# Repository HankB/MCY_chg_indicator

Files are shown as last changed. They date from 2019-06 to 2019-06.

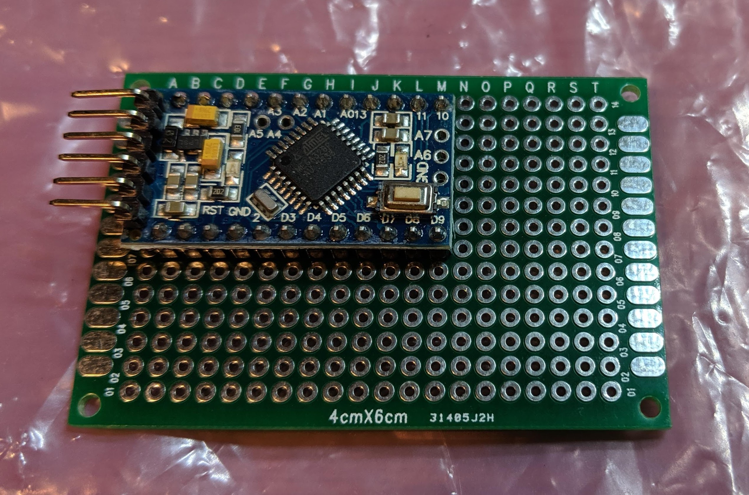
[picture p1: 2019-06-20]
IMG_20190619_212652.jpg

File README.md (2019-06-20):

# Control RGB color based on input voltage

## Motivation

When the electrical charging system on a motorcycle is heavily loaded, it may not keep the battery fully charged. The first symptom of that is that voltage will drop continuously until it is no longer sufficient to keep the engine running. The second symptom is that the motorcycle will stop running and/or may not restart. If there is an indication of system voltage, the issue can be dealt with (by shedding load) before the moto stops running. This project will produce an indication using an Arduino/AVR to monitor voltage and transition an RGB LED from green through yellow and to red to indicate charging status.

Secondary motivation is to help mark the passage of time. Many traffic lights won't detect the presence of a motorcycle and after some time it is allowed to proceed when traffic permits. Flash one, two, three and four times to mark passage of a minute. (15 second intervals.)

## Functionality

* Vary the color of the RGB LED from red -> yellow -> green to indicate system voltage.
* Flash (blip) the LED periodically to mark the passage of time.

## Hardware

* Arduino Pro Mini. (Or bare ATMEGA328P chip on PCB)
* Voltage regulator and filtering capacitors to convert nominal 12V power to 5.0V to power the system. L7805CV regulator with 0.47µF input and 0.22µF output filtering capacitors.
* Resistor voltage divider to reduce the moto system voltage to <5.0V needed for the ADC on the AVR. (1x 2.4KΩ and 1x 1.2KΩ resistors to provide a divider that will produce 5.0V from 15.0V.)
* Input protection for the ADC consisting of 1N5231B (5.1V) Zener diode with 820Ω resistor. [0]
* RGB LED with 3 2KΩ series resistors. That's fairly high resistance but otherwise the LED will be excessively bright during the day. ()

Connect the middle leg of the volume fader to A0 with outer legs connected to ground and 5V to provide a 0-5V analog input.
Connect the longest leg of the RGB LED to ground. When the ground is toward the left, the remaining pins are red, green and blue left to right respectively. Connect the LED inputs to the digital outputs indicated in the code.

## Other information

General description https://docs.google.com/document/d/1oGInpiPI6TI1JvXcmjz_O_Tvbv5o_kn_NtnWW1Aht5o/edit?usp=sharing
Resistor vs. ADC reading calculations https://docs.google.com/spreadsheets/d/1I-rtjzvy2xRRpHdrsMQctPhc0Ry49aa2tnfBnYBoY4o/edit?usp=sharing

## TODO

* Average several input readings for better noise rejection. - done
* Develop scaled analog input with protection - done on mock-up.
* Develop VR to power board from ~12V auto power - done on mock-up.
* Build a custom board with Pro Mini, power supply, analog input conditioning and outputs for the RGB LED. 

## Errata

When using the Inland Pro Mini 5V and providing it with 5V to Vcc, it reads full scale at ~4.7V. Treating the ADC as if it has a reference voltage of 4.7V produces readings over the range more closely match what is read using a DVM.

[0]I've studied the data sheet for the Zener diode and have no idea if the paired resistor is the right value to provide protection.

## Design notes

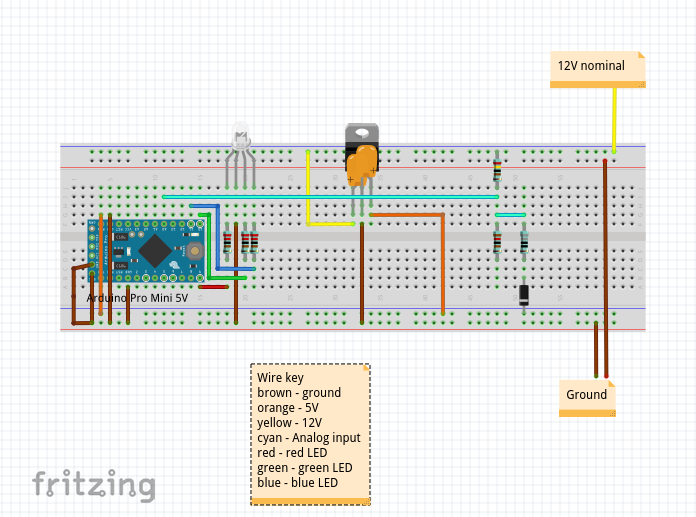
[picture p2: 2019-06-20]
breadboard.png

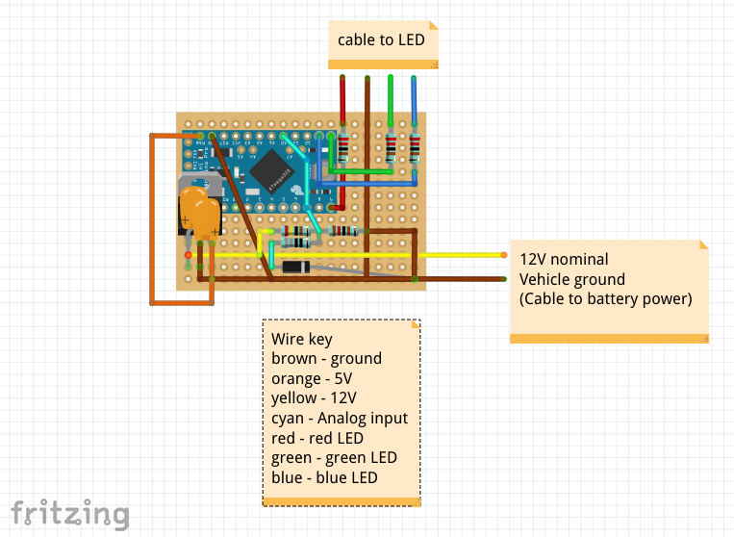
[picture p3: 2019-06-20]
protoboard.png

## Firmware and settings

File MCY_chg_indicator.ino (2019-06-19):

/*
  This sketch began life as the "Analog Input" example. Little of the original remains.
  created by David Cuartielles
  modified 30 Aug 2011
  By Tom Igoe

  This example code is in the public domain.

  http://www.arduino.cc/en/Tutorial/AnalogInput

  Monitor an analog input and illuminate an RGB LED to indicate evaluation of
  the charging voltage. Input volgate is scaled 1:3 so that 15V from the
  charging system would present 5.0V at the analog input.

  See https://docs.google.com/document/d/1oGInpiPI6TI1JvXcmjz_O_Tvbv5o_kn_NtnWW1Aht5o/edit?usp=sharing
  and https://docs.google.com/spreadsheets/d/1I-rtjzvy2xRRpHdrsMQctPhc0Ry49aa2tnfBnYBoY4o/edit?usp=sharing
  for further information.

*/

// thresholds based on apparent 4.7V ADC reference voltage when Pro Mini is provided with Vcc = 5.0V
static const uint16_t high = 1000;
static const uint16_t good = 921;
static const uint16_t marginal = 887;
static const uint16_t bad = 682;
static const uint16_t spread = good - bad;

// I really wish Arduino didn't hide the signatures for library finctions like pinMode()
static const int sensorPin =   A0;   // select the input pin for the potentiometer
static const int redPin =      9;   // select the pin for the LED
static const int greenpin =    10;
static const int bluePin =     11;

static uint16_t sensorValue = 0;    // variable to store the value coming from the sensor

const uint16_t red_pct = 50;
const uint16_t green_pct = 50;
const uint16_t max_DAC   = 255;

// blip the color periodically to time malfunctioning traffic lights
static const unsigned long  time_blip_period = 15 * 1000; // milliseconds for time blip period
static const unsigned long  time_blip_duration = 150;   // milliseconds duration for blip

#define SERIAL_OUT  0

void setup() {
  // declare the ledPin as an OUTPUT:
  pinMode(redPin, OUTPUT);
  pinMode(greenpin, OUTPUT);
  pinMode(bluePin, OUTPUT);
#if SERIAL_OUT
  Serial.begin(9600);
#endif //SERIAL_OUT
}

uint16_t readVoltage(void) {
  static const uint16_t analog_repeat =        8;  // consedutive analog readings to sum to reduce noise
  static const uint16_t analog_repeat_delay =  4;  // delay in ms between consecutive analog readings
  static uint16_t readings[analog_repeat];
  static uint16_t value;

  for (int i = 0; i < analog_repeat; i++) {
    readings[i] = analogRead(sensorPin);
    value += readings[i];
    delay(analog_repeat_delay);
  }
  value = (value + analog_repeat / 2) / analog_repeat;  // divide with rounding

#if SERIAL_OUT
  for (int i = 0; i < analog_repeat; i++) {
    Serial.print(readings[i]);
    Serial.print(" ");
  }
  Serial.print(" ");
  Serial.print(value);
#endif //SERIAL_OUT
  return value;
}

void setLEDcolor(uint16_t reading) {
  if (reading >= good) {
    analogWrite(greenpin, (max_DAC * green_pct) / 100);
    analogWrite(redPin, 0);
#if SERIAL_OUT
    Serial.print(" good ");
    Serial.println(reading);
    delay(1000);
#endif //SERIAL_OUT
  }
  else if (reading < bad) {
    analogWrite(greenpin, 0);
    analogWrite(redPin, (max_DAC * red_pct) / 100);
#if SERIAL_OUT
    Serial.print(" bad  ");
    Serial.println(reading);
    delay(1000);
#endif //SERIAL_OUT
  }
  else {
    uint16_t blend = (reading - bad) * 100 / spread; // calculate blend percent
    uint16_t green = blend * max_DAC / 100 * green_pct / 100;
    uint16_t red = (100 - blend) * max_DAC / 100 * red_pct / 100;
    analogWrite(greenpin, green);
    analogWrite(redPin, red);
#if SERIAL_OUT
    Serial.print(" betw ");   Serial.print(reading);
    Serial.print(" blend ");  Serial.print(blend);
    Serial.print(" green ");  Serial.print(green);
    Serial.print(" red ");    Serial.print(red);
    Serial.print(" sum ");    Serial.println(green + red);
    delay(1000);
#endif //SERIAL_OUT
  }

}

void blipIfTime(unsigned long time_now) {
  static unsigned long        time_blip_timer = time_blip_period;
  static unsigned int blip_repeat_counter = 0;
  static const unsigned int blip_repeat = 4;    // blip 1, 2, 3 and 4 times

  if (time_now >= time_blip_timer) {
    time_blip_timer = time_now + time_blip_period;
    for (int i = 0; i <= blip_repeat_counter; i++) {  // flash 1 - blip_repeat times
      analogWrite(greenpin, 0);
      analogWrite(redPin, 0);
      analogWrite(bluePin, 255);
      delay(time_blip_duration);
      analogWrite(bluePin, 0);
      setLEDcolor(readVoltage());
      delay(time_blip_duration);
    }
    blip_repeat_counter++;
    if (blip_repeat_counter >= blip_repeat) {
      blip_repeat_counter = 0;
    }
  }
}

  void loop() {
    // read the value from the sensor:
    sensorValue = readVoltage();

#if SERIAL_OUT
    Serial.print(" rounded ");
    Serial.print(sensorValue);
#endif //SERIAL_OUT

    setLEDcolor(sensorValue);

    blipIfTime(millis());

    delay(10);
  }

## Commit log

2019-06-20 fritzing curcuit diagram
    [automotive_voltage_indicator.fzz]
2019-06-20 picture of intended PCB build platform
2019-06-20 added ground wire and relocating
    [automotive_voltage_indicator.fzz]
2019-06-20 diagram on protoboard
    [automotive_voltage_indicator-01.fzz]
2019-06-20 image of layo8ut on proto-board
